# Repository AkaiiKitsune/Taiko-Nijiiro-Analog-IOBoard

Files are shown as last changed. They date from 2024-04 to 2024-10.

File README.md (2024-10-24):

# Analog Taiko IO Board - ESP32 S3 DevkitC1

**PLEASE NOTE THAT THIS DESIGN IS FLAWED AND NEEDS TO BE REDONE!**  
While it will work, this has massive noise issues and is currently not ready for use.

Open-source project to make your own Taiko no Tatsujin IO Board for PC use or SD cabs converted to Nijiiro.  
It emulates an analog joystick to enable force sensing, just like how you would play on an official arcade machine.

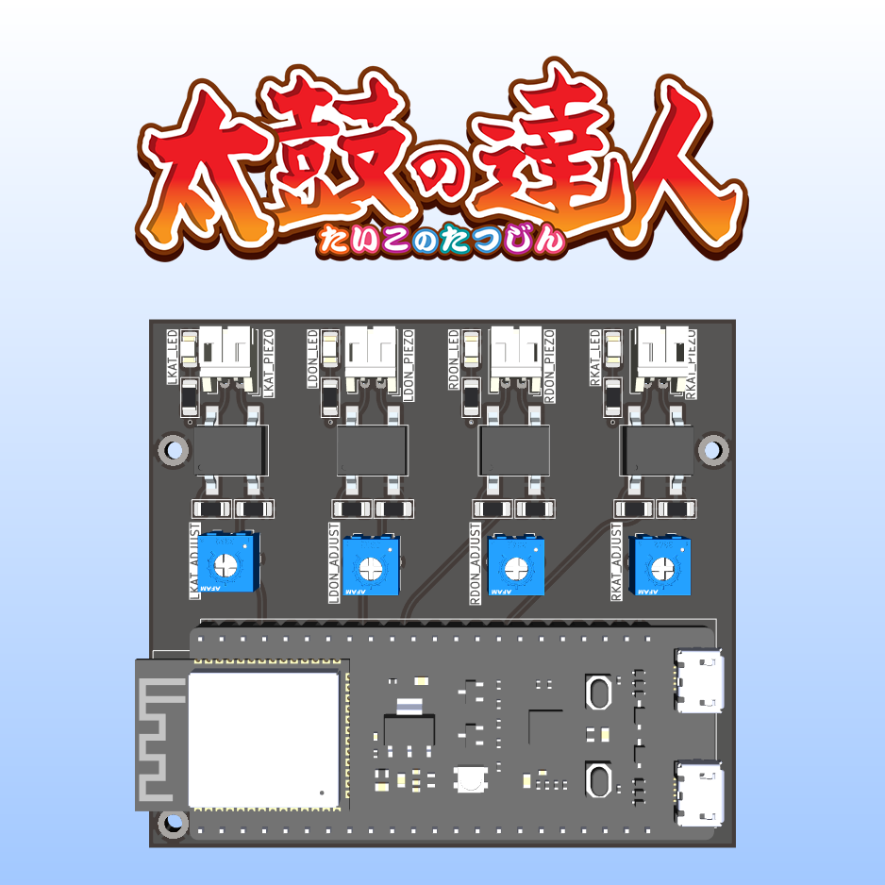
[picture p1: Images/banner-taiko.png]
Taiko Drum Controller


## Table of content

- [Analog Taiko IO Board - ESP32 S3 DevkitC1](#analog-taiko-io-board---esp32-s3-devkitc1)
  - [Table of content](#table-of-content)
  - [About this Project](#about-this-project)
  - [Components needed](#components-needed)
  - [Parameters tuning](#parameters-tuning)
    - [Player Selection](#player-selection)
    - [Sensitivity](#sensitivity)
  - [Additional Notes](#additional-notes)
    - [Why bridge rectifiers](#why-bridge-rectifiers)
    - [TaikoArcadeLoader](#taikoarcadeloader)

## About this Project

This is a hard fork of [ShikyC's](https://github.com/ShikyC/Taiko-Drum-Controller-Arduino) taiko controller project with some QOL improvements.  
It's aim is to provide accurate-enough arcade drum support for converted SD cabs or bootlegs running Taiko Nijiiro.
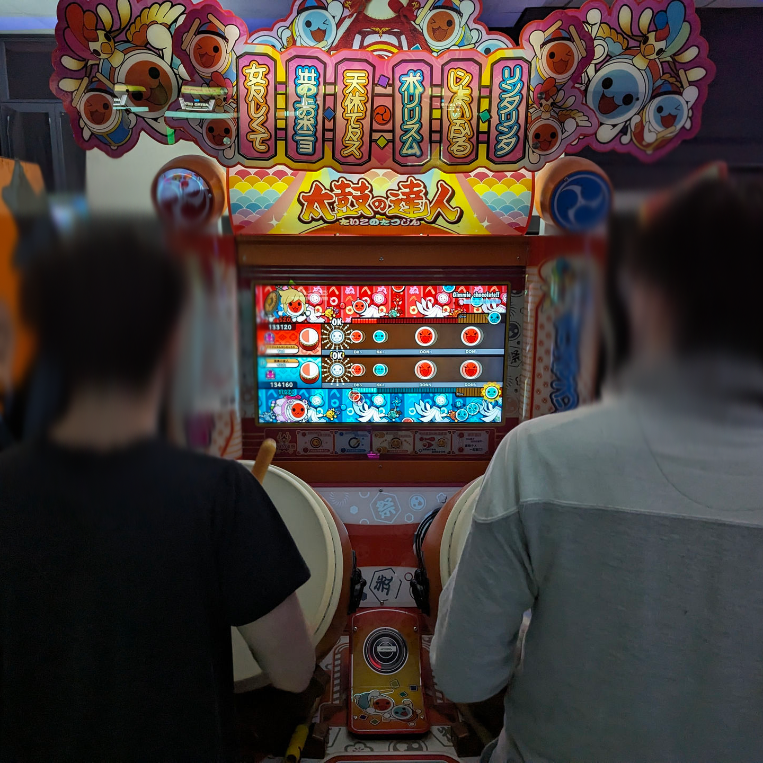
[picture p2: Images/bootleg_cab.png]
Converted bootleg cab

**This program is for personal and non-commercial use only.**

## Components needed

* An [ESP32 S3 DevKitC-1](https://docs.espressif.com/projects/esp-idf/en/stable/esp32s3/hw-reference/esp32s3/user-guide-devkitc-1.html) board.
* 4 [JST PH 2.0](https://fr.aliexpress.com/item/1005004067623293.html) connectors (i'm using 90° ones but straight ones work too).
* 4 [1206 LEDs](https://fr.aliexpress.com/item/1005005975741298.html) (2 Blue and 2 Red).
* 8 1206 100kΩ resistors.
* 4 bridge rectifier chips. This project uses [DB107S](https://www.rectron.com/public/product_datasheets/db101s-db107s.pdf) (see the Additional Notes section for details).
* 4 10k variable resistors. This project uses [3362P-1-103](https://www.mouser.fr/datasheet/2/54/3362-776956.pdf)

All of those parts can be found for next to nothing on aliexpress.

You'll also need an IO Board PCB (you can find the gerber files in [here](PCB/Export/)).
I've used [JLCPCB](https://jlcpcb.com/) to order mine.

## Parameters tuning

All the parameters are located in [params.h](Firmware/params.h).

### Player Selection

   By setting `#define PLAYER_SELECT` to either `1` or `2`, you can set what player the board will act as. If you're using two of these, make sure that they each are set to a different player to avoid issues.

   The buildin led of the ESP32 S3 DevKitC1 will be either red or blue depending on that value !

### Sensitivity

   Not all piezoelectric sensors are the same, and thus the captured signals from the 4 sensors may vary significantly. The sensitivity adjust trims are used to normalize those differences.  

   To facilitate setting those trims up, set `DEBUG` to `1`, flash the firmware, roll on one of the 4 areas of the drum, and visualize the graph from the output of the Serial Plotter.

   In the following example, the right-don area generates a much higher value than other 3, so you can adjust the `sensitivity` by turning the R_DON potentiometer to eliminate the issue.

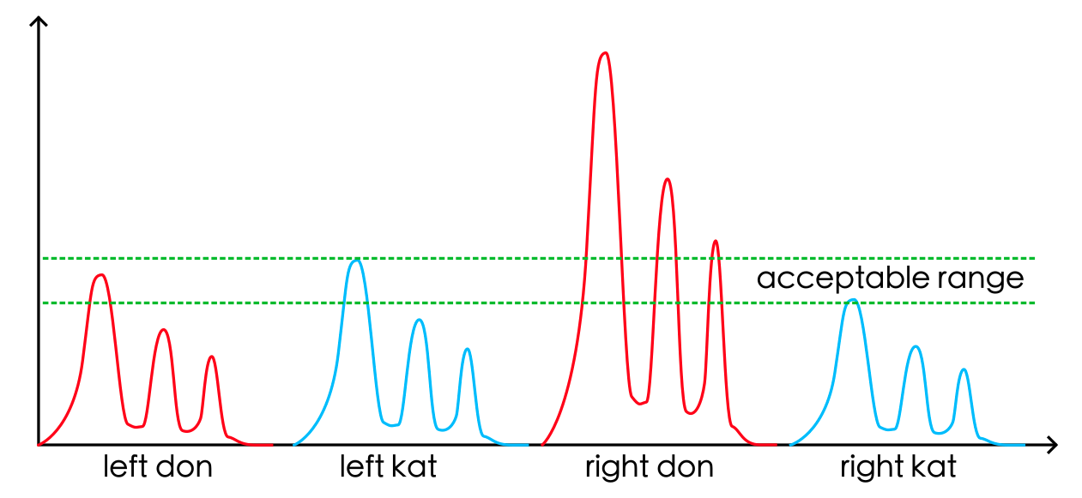
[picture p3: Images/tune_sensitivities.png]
Setting sensitivity values
   

   Note that the installation of the sensors is critical. You should make sure that the sensors are firmly attached on the wood and located properly, as seen on the picture below.

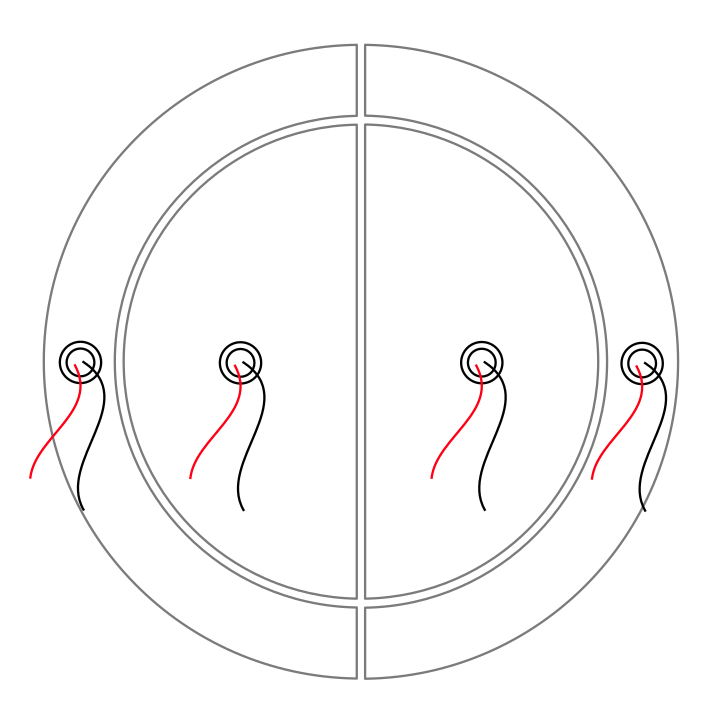
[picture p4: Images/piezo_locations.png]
Piezo locations
   

## Additional Notes

### Why bridge rectifiers

   Without biasing the voltage of the piezoelectric sensors, their output voltage range is about -5V to +5V. However, the ESP32 ADCs only accept positive voltage values from 0 to 3.3V. When they receive a negative voltage, it's simply truncated to 0.

   In a taiko drum, all the 4 vibrating pieces are connected together, meaning that if you hit left-don, the processor also receives signals from left-kat, right-don, and right-kat. If the left-don piezoelectric sensor generates a negative voltage at the beginning and is truncated by the ADC, it will cause a minor "delay" of about 3 to 4 milliseconds, and the processor could incorrectly treat this hit as a right-don, a left-kat, or even a right-kat, whichever sends a highest positive value.

   Using a bridge rectifier, all negative values are converted to positive. In other words, it's acting like a mathematical `abs()` function, ensuring that we don't miss any negative voltages.

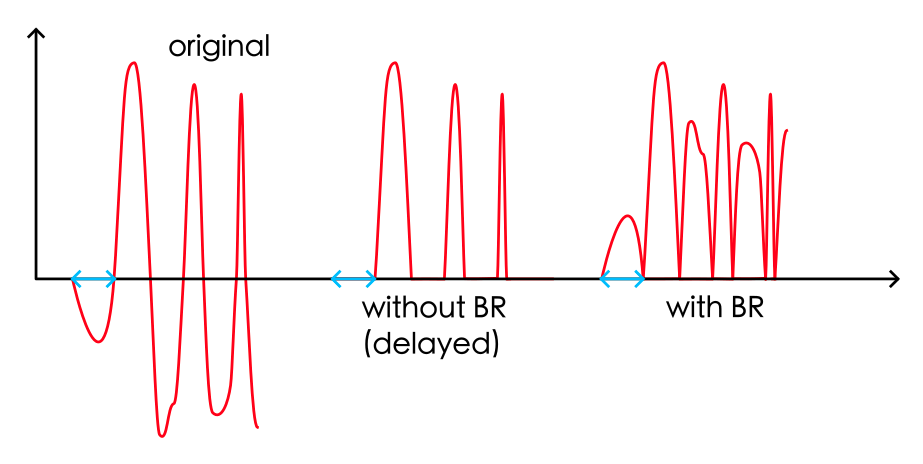
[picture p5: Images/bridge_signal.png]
Why using bridge rectifiers
   

### TaikoArcadeLoader

You'll need to use a recent version of esuo1198's fork of [TaikoArcadeLoader](https://github.com/esuo1198/TaikoArcadeLoader) (Commit [945e104](https://github.com/esuo1198/TaikoArcadeLoader/commit/945e104) and up).

Open `config.toml` and enable analog input like so :

```toml
   [controller]
   analog = true  
```

If the IO Board is detected but your game doesn't register any inputs, check in `gamecontrollerdb.txt` that you have the following entry under `#Windows`:

`030052a8694800006948000000000000,Nijiiro Analog IO Board,-leftx:-a0,+leftx:+a0,-lefty:-a1,+lefty:+a1,-rightx:-a2,+rightx:+a2,-righty:-a3,+righty:+a3,platform:Windows,`

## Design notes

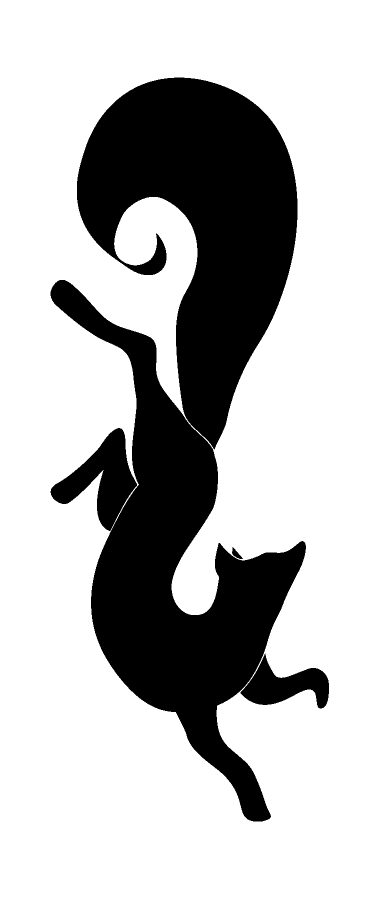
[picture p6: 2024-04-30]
PCB/Images/Fox.bmp

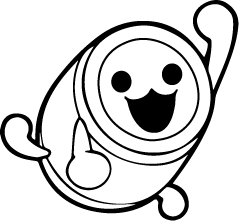
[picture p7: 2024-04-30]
PCB/Images/Don.bmp

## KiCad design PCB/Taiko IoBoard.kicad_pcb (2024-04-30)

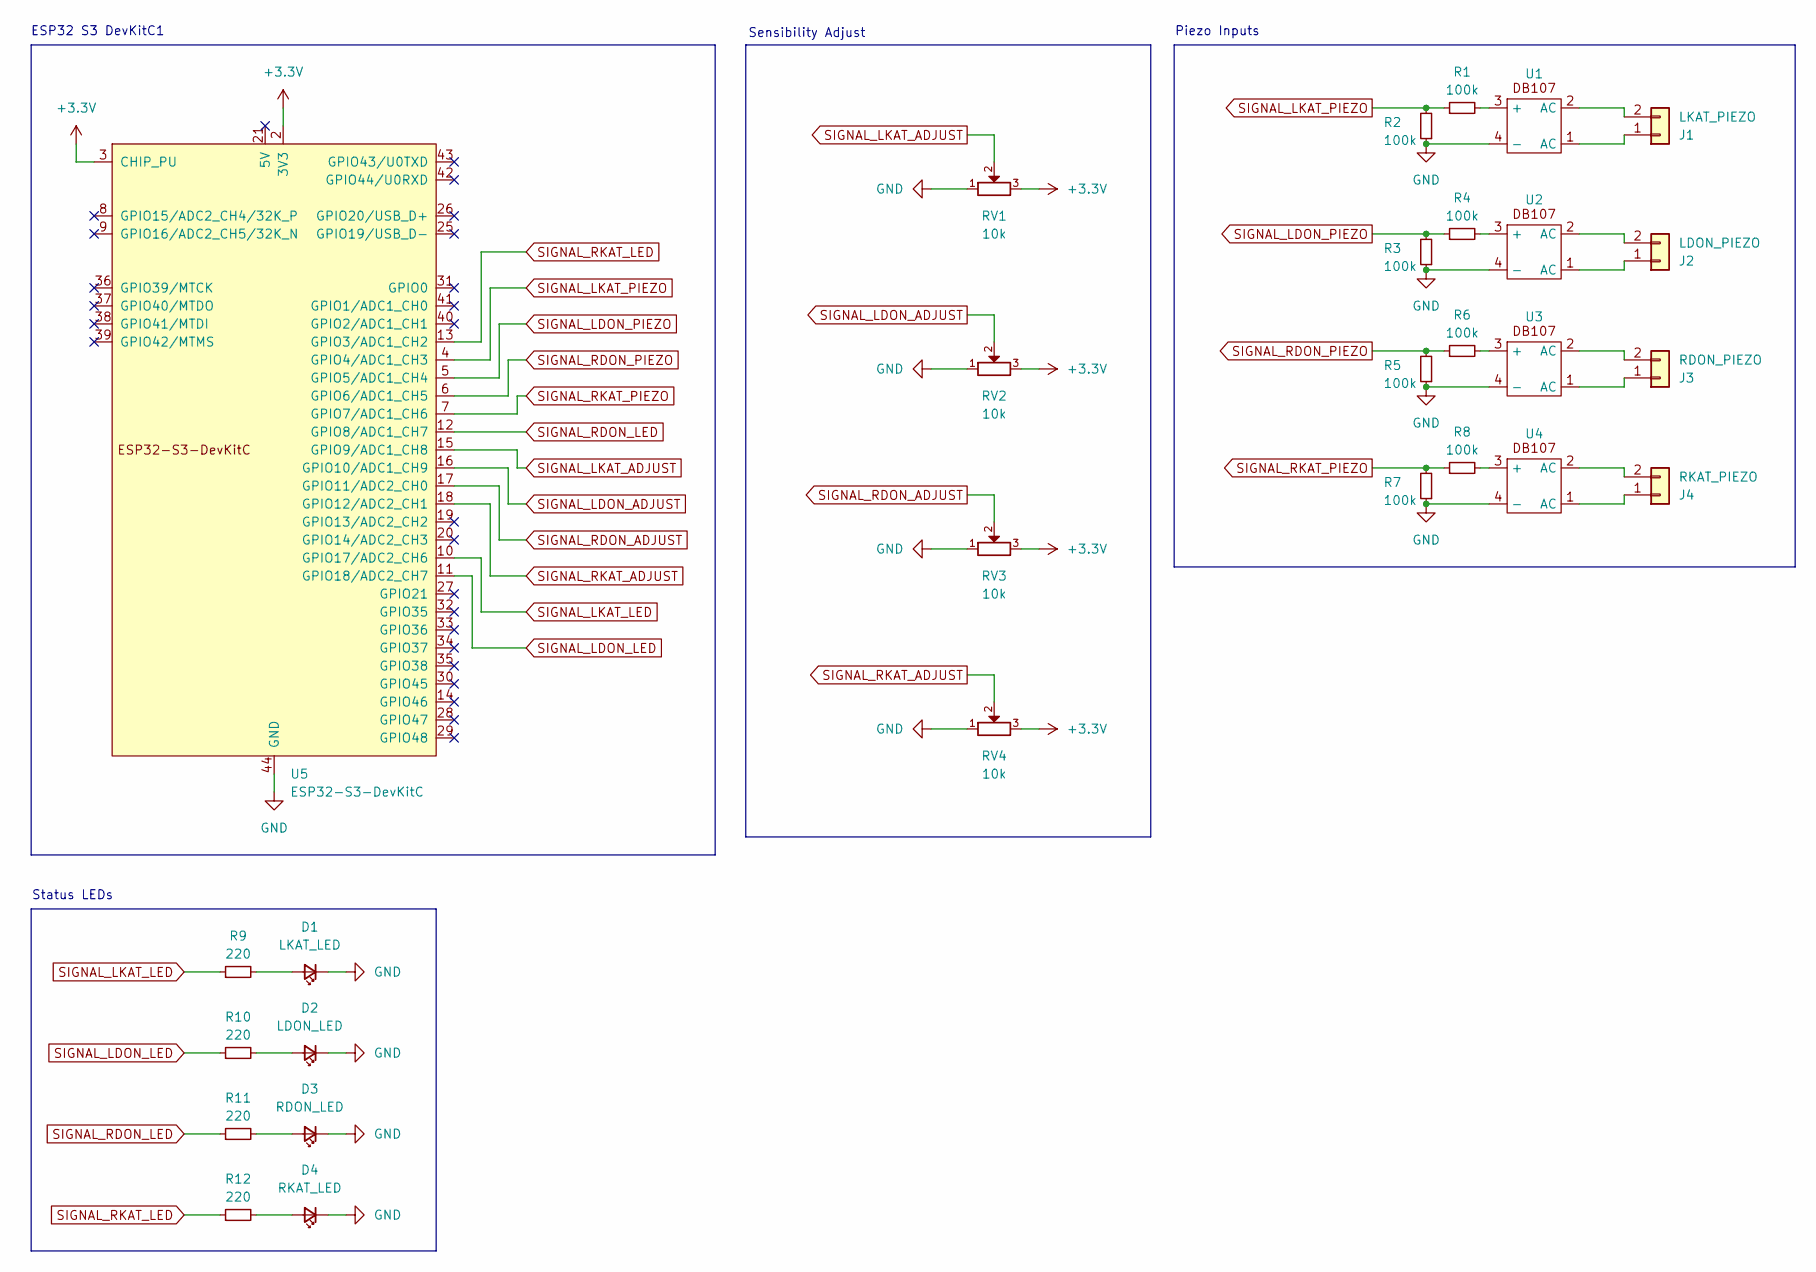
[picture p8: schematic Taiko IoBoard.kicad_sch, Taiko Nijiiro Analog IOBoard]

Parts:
D1: LKAT_LED; LED_1206_3216Metric_Pad1.42x1.75mm_HandSolder
D2: LDON_LED; LED_1206_3216Metric_Pad1.42x1.75mm_HandSolder
D3: RDON_LED; LED_1206_3216Metric_Pad1.42x1.75mm_HandSolder
D4: RKAT_LED; LED_1206_3216Metric_Pad1.42x1.75mm_HandSolder
J1: LKAT_PIEZO; TE_440055-2_1x02_P2.00mm_Horizontal
J2: LDON_PIEZO; TE_440055-2_1x02_P2.00mm_Horizontal
J3: RDON_PIEZO; TE_440055-2_1x02_P2.00mm_Horizontal
J4: RKAT_PIEZO; TE_440055-2_1x02_P2.00mm_Horizontal
R1, R2, R3, R4, R5, R6, R7, R8: 100k; R_1206_3216Metric_Pad1.30x1.75mm_HandSolder
R9, R10, R11, R12: 220; R_1206_3216Metric_Pad1.30x1.75mm_HandSolder
RV1, RV2, RV3, RV4: 10k; potentiometer_3362P
U1, U2, U3, U4: DB10X SOP4
U5: ESP32-S3-DevKitC

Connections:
+3.3V: RV1.3, RV2.3, RV3.3, RV4.3, U5.1 (3V3), U5.2 (3V3), U5.3 (CHIP_PU)
GND: D1.1 (K), D2.1 (K), D3.1 (K), D4.1 (K), R2.1, R3.1, R5.1, R7.1, RV1.1, RV2.1, RV3.1, RV4.1, U1.4 (-), U2.4 (-), U3.4 (-), U4.4 (-), U5.22 (GND), U5.23 (GND), U5.24 (GND), U5.44 (GND)
unnamed: D1.2 (A), R9.2
unnamed: D2.2 (A), R10.2
unnamed: D3.2 (A), R11.2
unnamed: D4.2 (A), R12.2
unnamed: J1.1, U1.1 (AC)
unnamed: J1.2, U1.2 (AC)
unnamed: J2.1, U2.1 (AC)
unnamed: J2.2, U2.2 (AC)
unnamed: J3.1, U3.1 (AC)
unnamed: J3.2, U3.2 (AC)
unnamed: J4.1, U4.1 (AC)
unnamed: J4.2, U4.2 (AC)
unnamed: R1.2, U1.3 (+)
unnamed: R4.2, U2.3 (+)
unnamed: R6.2, U3.3 (+)
unnamed: R8.2, U4.3 (+)
SIGNAL_LDON_ADJUST: RV2.2, U5.16 (GPIO10/ADC1_CH9)
SIGNAL_LDON_LED: R10.1, U5.11 (GPIO18/ADC2_CH7)
SIGNAL_LDON_PIEZO: R3.2, R4.1, U5.5 (GPIO5/ADC1_CH4)
SIGNAL_LKAT_ADJUST: RV1.2, U5.15 (GPIO9/ADC1_CH8)
SIGNAL_LKAT_LED: R9.1, U5.10 (GPIO17/ADC2_CH6)
SIGNAL_LKAT_PIEZO: R1.1, R2.2, U5.4 (GPIO4/ADC1_CH3)
SIGNAL_RDON_ADJUST: RV3.2, U5.17 (GPIO11/ADC2_CH0)
SIGNAL_RDON_LED: R11.1, U5.12 (GPIO8/ADC1_CH7)
SIGNAL_RDON_PIEZO: R5.2, R6.1, U5.6 (GPIO6/ADC1_CH5)
SIGNAL_RKAT_ADJUST: RV4.2, U5.18 (GPIO12/ADC2_CH1)
SIGNAL_RKAT_LED: R12.1, U5.13 (GPIO3/ADC1_CH2)
SIGNAL_RKAT_PIEZO: R7.2, R8.1, U5.7 (GPIO7/ADC1_CH6)

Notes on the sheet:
ESP32 S3 DevKitC1
Sensibility Adjust
Piezo Inputs
Status LEDs

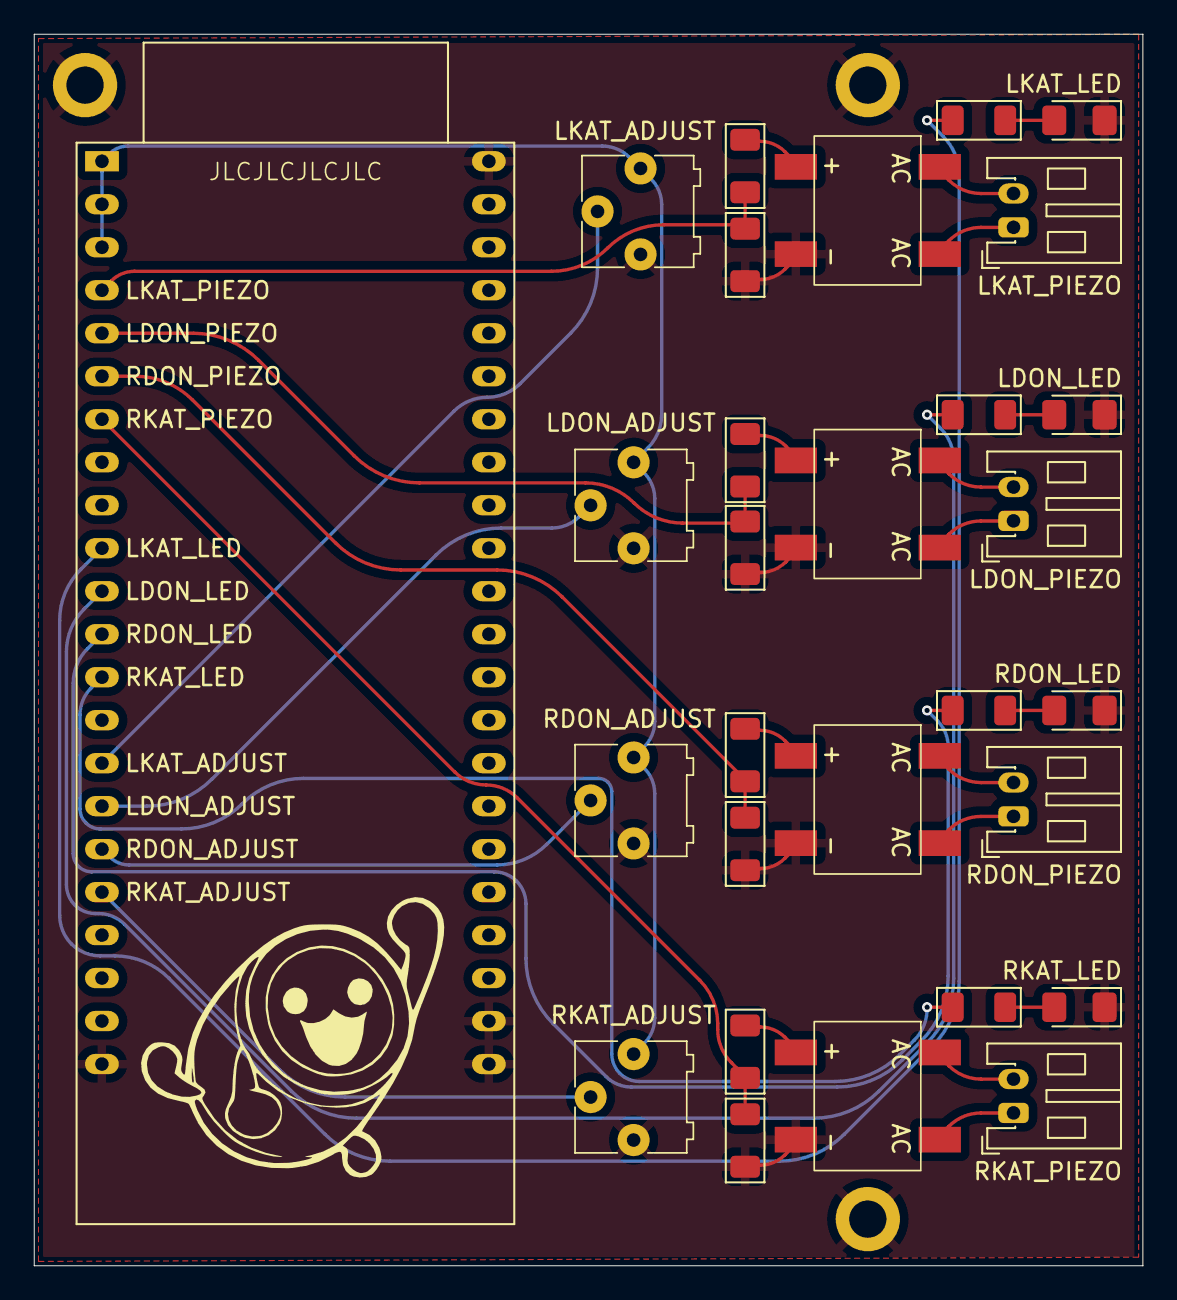
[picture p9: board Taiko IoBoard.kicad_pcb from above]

Board: 2 copper layers, 65.5 x 72.8 mm, 29 parts (0 on the bottom side), 30 nets.

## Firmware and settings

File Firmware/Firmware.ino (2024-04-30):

/****************************************************
  IF YOU WANT TO CHANGE THE SETTINGS GO TO params.h !
*****************************************************/
#include <FastLED.h>
#include "params.h"

CRGB player_led[1];

const byte inPins[CHANNELS] = {
    L_DON_IN, L_KAT_IN, R_DON_IN, R_KAT_IN};
const byte sensitivityPins[CHANNELS] = {
    L_DON_ADJUST, L_KAT_ADJUST, R_DON_ADJUST, R_KAT_ADJUST};

const byte ledPins[CHANNELS] = {
    L_DON_LED, L_KAT_LED, R_DON_LED, R_KAT_LED};

Cache<int, SAMPLE_CACHE_LENGTH> inputWindow[CHANNELS];
unsigned long power[CHANNELS];

uint axisValues[CHANNELS] = {0, 0, 0, 0};

Joystick_ Joystick(JOYSTICK_DEFAULT_REPORT_ID, JOYSTICK_TYPE_GAMEPAD, 10, 4, true, true, false, true, true, false, false, false, false, false, false);

// ===================================================================================================
void setup()
{
#if DEBUG
  Serial.begin(250000);
#endif

  // Setting the internal ESP32 RGB LED to the player's color :
  // Red for player 1, Blue for player 2.
  FastLED.addLeds<NEOPIXEL, 48>(player_led, 1); // gpio48
  player_led[0] = PLAYER_SELECT == 1 ? CRGB::Red : CRGB::Aqua;
  FastLED.show();

  for (byte i = 0; i < CHANNELS; i++)
  { // Set pin mode for all input, sensitivity; and LED pins.
    pinMode(inPins[i], INPUT);
    pinMode(sensitivityPins[i], INPUT);
    pinMode(ledPins[i], OUTPUT);

    ledcSetup(i, ledFreq, ledResolution); // Init all ledc channels.
    ledcAttachPin(ledPins[i], i);         // Attach each LEDs to a different ledc pwm channel.

    // Then init the array(s) which will hold the piezzos values on each cycle.
    power[i] = 0;
  }

  // Init USB
  USB.PID(0x4869);
  USB.VID(0x4869);
  USB.productName("Nijiiro Analog IO Board");
  USB.manufacturerName("ShikyC, AkaiiKitsune");

  USB.begin();

  // Init Joystick
  Joystick.begin(false);
  Joystick.setXAxisRange(-AXIS_RANGE, AXIS_RANGE);
  Joystick.setYAxisRange(-AXIS_RANGE, AXIS_RANGE);
  Joystick.setRxAxisRange(-AXIS_RANGE, AXIS_RANGE);
  Joystick.setRyAxisRange(-AXIS_RANGE, AXIS_RANGE);
}

// ===================================================================================================
void loop()
{
  for (byte i = 0; i < CHANNELS; i++)
  {
    inputWindow[i].put(analogRead(inPins[i]));
    power[i] = power[i] - inputWindow[i].get(1) + inputWindow[i].get();

    float x = analogRead(sensitivityPins[i]) / 2048.0 - 1;
    float x2 = x * x;
    float x3 = x2 * x;
    float x4 = x3 * x;
    float v = (1.0 + x + 0.5 * x2 + 0.166667 * x3) * power[i];
    axisValues[i] = AXIS_RANGE * (v >= MAX_THRES ? 1 : (v / MAX_THRES));

#if DEBUG
    Serial.print("Channel_" + String(i) + ":");
    if (i < CHANNELS - 1)
      Serial.print(power[i] + ",");
    else
      Serial.println(power[i]);
#endif

    ledcWrite(i, (int)((axisValues[i] / AXIS_RANGE) * 255));
  }

#if PLAYER_SELECT == 1
  Joystick.setXAxis(axisValues[0] > axisValues[1] ? axisValues[0] : -axisValues[1]);
  Joystick.setYAxis(axisValues[2] > axisValues[3] ? axisValues[2] : -axisValues[3]);
  Joystick.setRxAxis(0);
  Joystick.setRyAxis(0);
#elif PLAYER_SELECT == 2
  Joystick.setXAxis(0);
  Joystick.setYAxis(0);
  Joystick.setRxAxis(axisValues[0] > axisValues[1] ? axisValues[0] : -axisValues[1]);
  Joystick.setRyAxis(axisValues[2] > axisValues[3] ? axisValues[2] : -axisValues[3]);
#else
  Joystick.setXAxis(0);
  Joystick.setYAxis(0);
  Joystick.setRxAxis(0);
  Joystick.setRyAxis(0);
#endif

  Joystick.sendState();
}

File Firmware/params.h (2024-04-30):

// Select which player this board is. 1 for P1 and 2 for P2.
#define PLAYER_SELECT 1

// Enable debug mode to view analog input values from Serial.
// Make sure to use the serial plotter and not the serial monitor!
#define DEBUG 0

/**********************************************
  EVERYTHING BEYOND THIS POINT DOESN'T NEED TO
   BE EDITED EXCEPT IF YOU MODIFIED THE PCB !
***********************************************/
// ============ PIN DEFINITION ================
// Input pins.
#define L_KAT_IN 4
#define L_DON_IN 5
#define R_DON_IN 6
#define R_KAT_IN 7

// Sensitivity adjustment potentiometer input pins.
#define L_KAT_ADJUST 9
#define L_DON_ADJUST 10
#define R_DON_ADJUST 11
#define R_KAT_ADJUST 12

// LED pins.
#define L_KAT_LED 17
#define L_DON_LED 18
#define R_DON_LED 8
#define R_KAT_LED 3

// ============ OTHER SETTINGS ================
// The maximum value of a hit (not the minumum value to trigger a heavy hit)
// To configure the light and heavy thresholds, do it in the game settings.
#define MAX_THRES 5000

// LED PWM Settings.
#define ledFreq 1000
#define ledResolution 8

// Sampling Cache, a higher value means a smoother signal. 32 is a good value for the esp32.
// This value must be a power of 2 (4, 8, 16, 32, etc).
#define SAMPLE_CACHE_LENGTH 32

#define AXIS_RANGE 1023
#define PLAYERS 2
#define CHANNELS 4

#include <USB.h>
#include "joystick.h"
#include "cache.h"
